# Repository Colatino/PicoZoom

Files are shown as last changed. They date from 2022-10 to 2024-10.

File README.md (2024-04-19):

# PicoZoom

A MIDI controller for Zoom pedals based on the Raspberry pi Pico.
 
This project is the microcontroler version of the [one](https://github.com/Colatino/ZeroPedal) I've built with a Raspberry Pi Zero

The purpose of this project is to build an auxiliary pedal controller to be used with Zoom multi-effects processors like the G1XFour (tested with this model) and be able to toggle individual effects on/off, add a tap-tempo functionality, among other possible features.

This project wouldn't be possible without [zoom-zt2](https://github.com/mungewell/zoom-zt2) and [ZoomPedalFun](https://github.com/shooking/ZoomPedalFun).

## HOW TO BUILD ONE

### CODE
You'll have to install the [Arduino IDE](https://www.arduino.cc/en/software) and add the [Arduino-pico core](https://github.com/earlephilhower/arduino-pico) to it, follow the [installation instructions](https://arduino-pico.readthedocs.io/en/latest/install.html) on the documentation. Tested with version 2.5, newer versions may not be compatible.

This project makes use of the following libraries:
- A custom version of [Adafruit_TinyUSB_Arduino](https://github.com/adafruit/Adafruit_TinyUSB_Arduino) based on [rppicomidi's fork](https://github.com/rppicomidi/tinyusb/tree/pio-midihost) of [tinyusb](https://github.com/hathach/tinyusb)
- [Adafruit_SSD1306](https://github.com/adafruit/Adafruit_SSD1306) and its dependencies
- [Arduino MIDI](https://github.com/FortySevenEffects/arduino_midi_library)

Copy the custom [Adafruit_TinyUSB_Arduino](https://github.com/Colatino/PicoZoom/tree/main/lib/Adafruit_TinyUSB_Library) library to you Arduino/libraries folder, be careful if you already have the original one installed as it will be overwritten.

Open the *.ino file and change whatever lines you need, you might want to change these lines to match your setup:
```cpp
#define NUM_PEDALS 5 // Number of switches and screens - for now each switch has to be linked to an oled screen
int switch_pins[] = { 5, 6, 7, 8, 9 }; // GPIO pins on the pico the switches are attached to 
FootSwitch footswitch[NUM_PEDALS];

int buses[] = { 7, 6, 5, 4, 3 }; // Buses on the TCA9548A the oled screens are attached to
Oled oleds[NUM_PEDALS];
```

For the G1XFour (possibly also the G1Four) no other line has to be changed.

On the IDE, go to Tools -> Board and select the Raspberry Pi Pico board (or other compatible) and select the appropriate comm Port. 

Then again Tools -> CPU Speed and set it to 120 MHz (this is crucial for the USB over PIO) and Tools -> USB Stack and set it to Adafruit TinyUSB.

Click upload and it will be compiled and sent to the board. 

If the IDE can't find the board, unplug it, hold the Bootsel button and plug it again. The PC will recognize it as a flash drive then on the IDE go to Sketch -> Export compiled binary and, after it is compiled, go to the sketch's folder and into the build folder look for the .UF2 file and drag and drop it on the Pico drive, all done.

### HARDWARE

To build it you'll need the following (G1XFour/G1Four):
- 1 x Raspberry Pi Pico (or a RP2040 based board)
- 5 x SSD1306 0.91" oled displays
- 1 x TC9548A
- 5 x SPST momentary footswitches
- 1 x female USB type A breakout board
- Some jumper wires
- Some box or case to contain everything - mine will be 3d printed and the files available on the case folder

Follow this wiring diagram (change GPIO if needed)
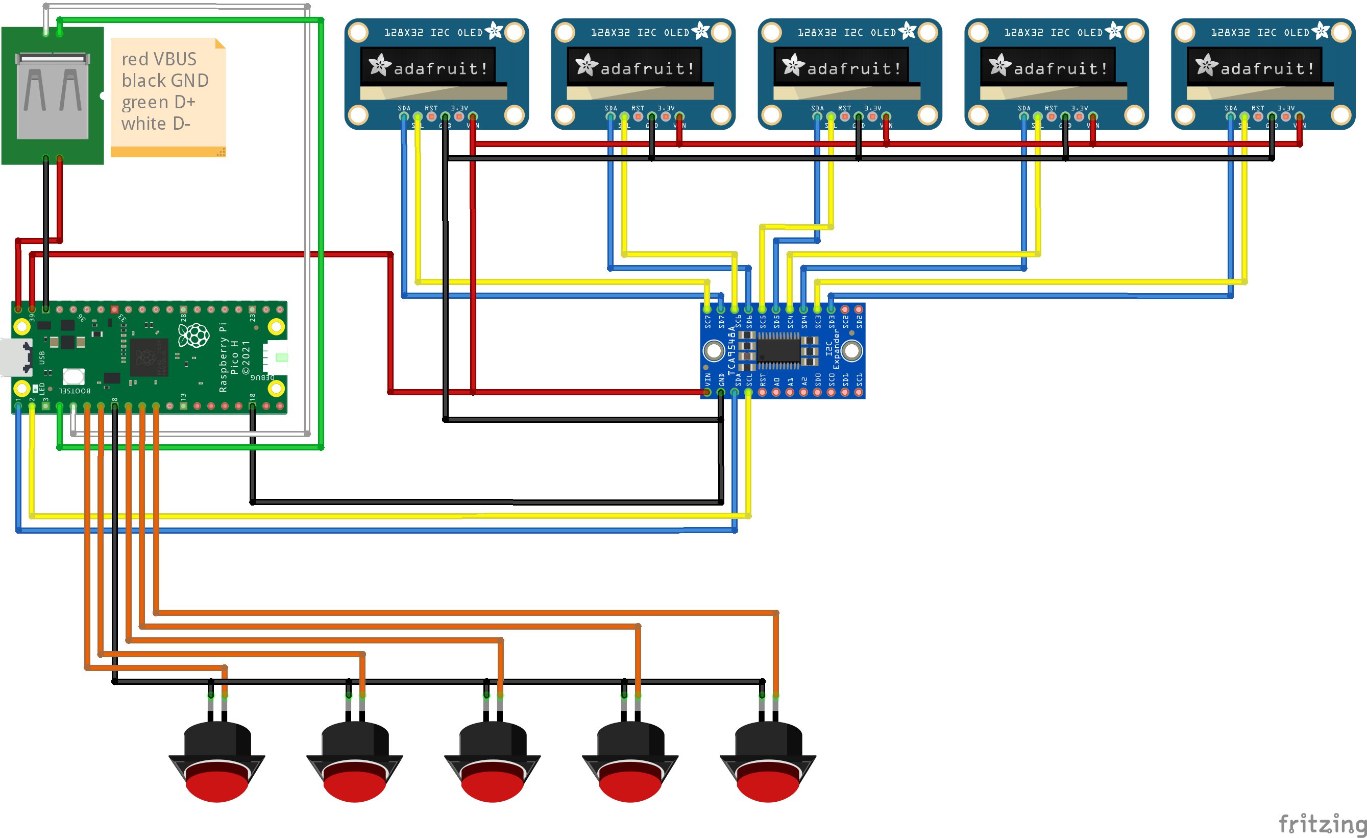
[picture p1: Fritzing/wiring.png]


I recommend not to use headers but instead solder the jumper wires to the TCA9548A as it may, sometimes, get loose.

After all the connections are made, I recommend that before you assembly the controller, test it with the Pedal as it will be harder to debug later.

If all goes well, just put everything inside the box ([stl/3mf files for 3d printing](https://github.com/Colatino/PicoZoom/tree/main/Case)) and you're done!

## How to use

Power the controller through the Pico's micro USB port (5V required, 1+ amps prefered) then connect it to the Pedal's own micro USB. The controller will provide power to the pedal and then it will read the pedal's data and show the current patch effects on the OLED screens. 

### Toggling effects

To toggle individual effects on/off just step on the corresponding switch, an active effect will have its name visible like -DELAY-, while an inactive one will have a strikethrough like ~~-DELAY-~~.

This is a video showing how it behaves when plugging and toggling effects:
Sample video (https://www.youtube.com/watch?v=8XPy8AvLA0o)

### Tap tempo/BPM

The tap tempo feature works when you have a delay effect on the current patch. 
To use it you'll have to hold its corresponding footswitch for at least 1 second, the OLED screen will then show the message *TAP TEMPO*, then you just have to press/tap the switch at the desire interval and the controller will show the current measured time between taps. When you're satisfied just stop tapping and wait for 3 seconds, the controller will send the measured interval to the pedal and will go back to the normal functions, showing the effect's name again. See the video bellow for a sample of how it works:

Tap tempo sample (https://youtu.be/NjomxG56lNE)

The global BPM feature works similarly but will ONLY be enabled when holding on any switch the DOES NOT correspond to a delay effect for 1 second. After activated a message *GLOBAL BPM* will show on the screen, then you just have to press/tap the switch at the desire interval and the controller will calculate the BPMs corresponding to that interval and show it on the screen. When you're satisfied just stop tapping and wait for 3 seconds, the controller will send the measured interval to the pedal and will go back to the normal functions, showing the effect's name again. See the video bellow for a sample of how it works:

Global tempo sample (https://youtu.be/VsWXhOvHJVc)

### ROADMAP
- [x] Ensure USB communications
- [x] Detect pedal plug/unplug
- [x] Handle MIDI packets
  - [x] Get pedal model/vid/pid
  - [x] Get current patch
    - [x] Get current patch effects state (on/off)
    - [x] Set current patch effect state (on/off)    
  - [x] Implement tap tempo
  - [x] Implement change global BPM
- [x] Handle footswitch press
- [x] Handle OLEDs
- [x] Create wiring diagram
- [x] Record and publish sample videos
- [x] Write a step-by-step guide
- [ ] Improve README
- [ ] Support other Zoom pedals by default?
- [ ] Add a battery?

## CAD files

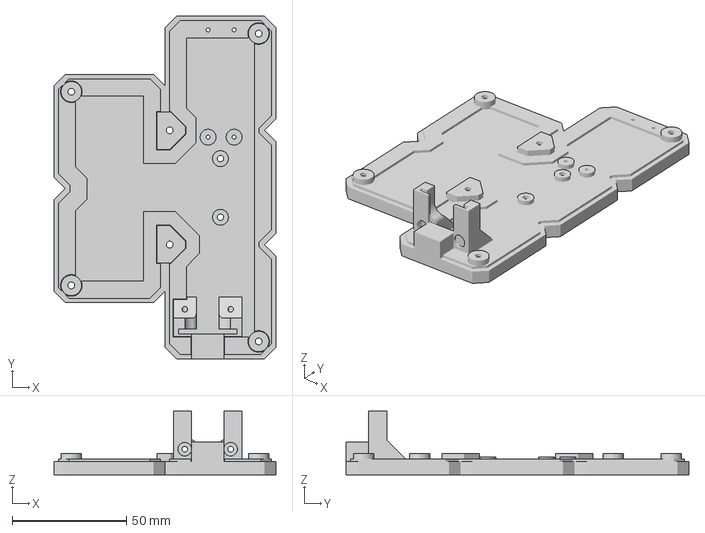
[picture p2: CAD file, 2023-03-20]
case/basev2.3mf
97.2 x 150.0 x 28.0 mm

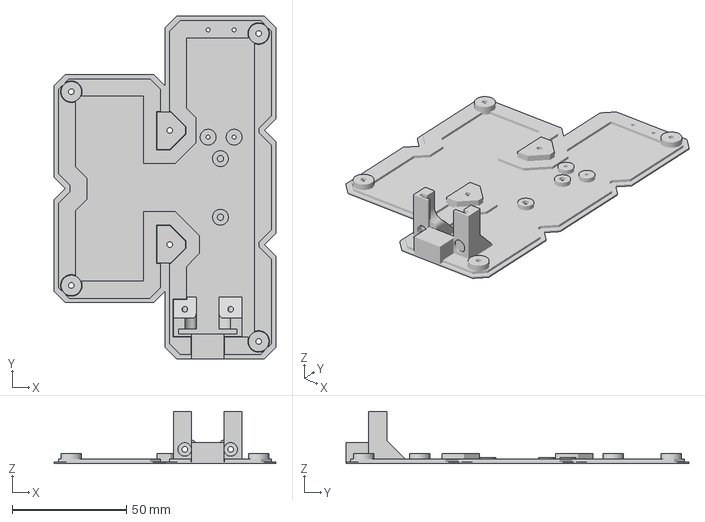
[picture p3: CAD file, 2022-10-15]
Case/base.3mf
97.2 x 150.0 x 23.0 mm

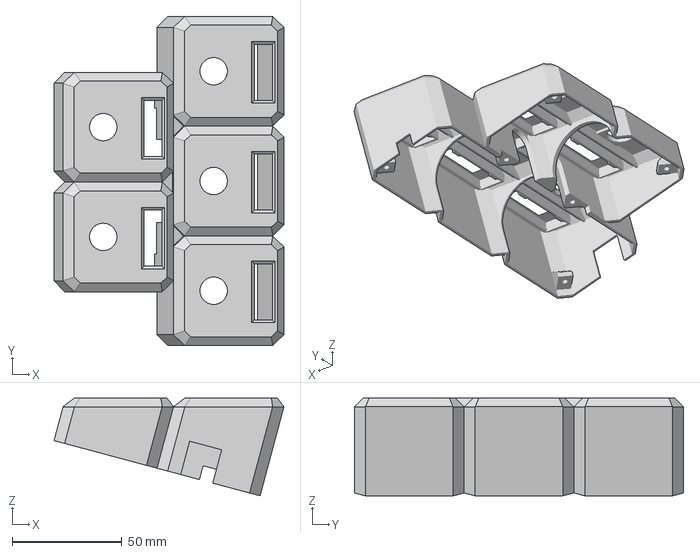
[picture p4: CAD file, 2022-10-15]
Case/top.3mf
104.8 x 150.0 x 44.5 mm

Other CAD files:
Case/base.stl
Case/top.stl
case/basev2.stl

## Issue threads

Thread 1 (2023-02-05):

Compile error on " function 'void poll_midi_host_rx()"

MarcosHAC, 2023-02-05:
Hi

this is a great project. It will help me play at church for sure. I got all the libraries and dependencies I found ([Adafruit_TinyUSB_Arduino](https://github.com/adafruit/Adafruit_TinyUSB_Arduino), [Pico-PIO-USB](https://github.com/sekigon-gonnoc/Pico-PIO-USB), [Adafruit_SSD1306](https://github.com/adafruit/Adafruit_SSD1306), [Adafruit-GFX-Library](https://github.com/adafruit/Adafruit-GFX-Library), [Adafruit_BusIO](https://github.com/adafruit/Adafruit_BusIO), [arduino_midi_library](https://github.com/FortySevenEffects/arduino_midi_library)). I also selected the board as instructed on Github (Pico). When I do a Verify on the code, I am getting the following error. It seems either a declare is nissing n the code, or I have a missing library. Please help to get this fixed. Thank you.

Arduino: 1.8.19 (Linux), Board: "Raspberry Pi Pico, 2MB (no FS), 120 MHz, Small (-Os) (standard), Disabled, Disabled, Disabled, Disabled, None, Adafruit TinyUSB, IPv4 Only, Default (UF2)"

../Documents/Pedal/beta/beta.ino: In function 'void poll_midi_host_rx()':
beta:771:10: error: 'tuh_midi_configured' was not declared in this scope; did you mean 'tuh_configure'?
  771 |     if (!tuh_midi_configured(midi_dev_addr)) {
      |          ^~~~~~~~~~~~~~~~~~~
      |          tuh_configure
beta:777:9: error: 'tuh_midih_get_num_rx_cables' was not declared in this scope
  777 |     if (tuh_midih_get_num_rx_cables(midi_dev_addr) < 1) {
      |         ^~~~~~~~~~~~~~~~~~~~~~~~~~~
beta:781:5: error: 'tuh_midi_read_poll' was not declared in this scope; did you mean 'tud_midi_read'?
  781 |     tuh_midi_read_poll(midi_dev_addr);
      |     ^~~~~~~~~~~~~~~~~~
      |     tud_midi_read
/home/marcos/Documents/Pedal/beta/beta.ino: In function 'void midi_host_task()':
beta:790:5: error: 'tuh_midi_stream_flush' was not declared in this scope; did you mean 'tud_midi_stream_write'?
  790 |     tuh_midi_stream_flush(midi_dev_addr);
      |     ^~~~~~~~~~~~~~~~~~~~~
      |     tud_midi_stream_write
/home/marcos/Documents/Pedal/beta/beta.ino: In function 'void send_sysex(uint8_t*, int)':
beta:878:5: error: 'tuh_midi_packet_write' was not declared in this scope; did you mean 'tud_midi_packet_write'?
  878 |     tuh_midi_packet_write(midi_dev_addr, packet);
      |     ^~~~~~~~~~~~~~~~~~~~~
      |     tud_midi_packet_write
/home/marcos/Documents/Pedal/beta/beta.ino: In function 'void tuh_midi_rx_cb(uint8_t, uint32_t)':
beta:930:11: error: 'tuh_midi_packet_read' was not declared in this scope; did you mean 'tud_midi_packet_read'?
  930 |       if (tuh_midi_packet_read(dev_addr, packet)) {
      |           ^~~~~~~~~~~~~~~~~~~~
      |           tud_midi_packet_read

'tuh_midi_configured' was not declared in this scope; did you mean 'tuh_configure'?

Colatino, 2023-02-05:
Hey Marcos, I will gladly help you!

It seems that you're not using my modified Adafruit_tinyusb library. Later today I'll have a look at it and try to come with a solution.

MarcosHAC, 2023-02-05:
Obrigado pela dica!!

I replaced the github tinyusb library with the one you provided and code is now compiling!!! Thank you!!!!

Colatino, 2023-02-05:
> Obrigado pela dica!!
>
> I replaced the github tinyusb library with the one you provided and code is now compiling!!! Thank you!!!!

Glad I could be of help.

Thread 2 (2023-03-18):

Ajuda com codigo

Bassgomes, 2023-03-18:
Olá André, estou com dificuldades de fazer o codigo funcionar

Bassgomes, 2023-03-18:
Primeiro erro foi de pio_usb.h, então procurei na biblioteca do arduino e encontrei uma e instalei, até que corrigiu esse erro.. agora apareceu outro...

C:\Users\bassg\Desktop\PicoZoom-main\src\beta\beta.ino: In function 'void poll_midi_host_rx()':
C:\Users\bassg\Desktop\PicoZoom-main\src\beta\beta.ino:771:10: error: 'tuh_midi_configured' was not declared in this scope; did you mean 'tuh_configure'?
  771 |     if (!tuh_midi_configured(midi_dev_addr)) {
      |          ^~~~~~~~~~~~~~~~~~~
      |          tuh_configure
C:\Users\bassg\Desktop\PicoZoom-main\src\beta\beta.ino:777:9: error: 'tuh_midih_get_num_rx_cables' was not declared in this scope
  777 |     if (tuh_midih_get_num_rx_cables(midi_dev_addr) < 1) {
      |         ^~~~~~~~~~~~~~~~~~~~~~~~~~~
C:\Users\bassg\Desktop\PicoZoom-main\src\beta\beta.ino:781:5: error: 'tuh_midi_read_poll' was not declared in this scope; did you mean 'tud_midi_read'?
  781 |     tuh_midi_read_poll(midi_dev_addr);
      |     ^~~~~~~~~~~~~~~~~~
      |     tud_midi_read
C:\Users\bassg\Desktop\PicoZoom-main\src\beta\beta.ino: In function 'void midi_host_task()':
C:\Users\bassg\Desktop\PicoZoom-main\src\beta\beta.ino:790:5: error: 'tuh_midi_stream_flush' was not declared in this scope; did you mean 'tud_midi_stream_write'?
  790 |     tuh_midi_stream_flush(midi_dev_addr);
      |     ^~~~~~~~~~~~~~~~~~~~~
      |     tud_midi_stream_write
C:\Users\bassg\Desktop\PicoZoom-main\src\beta\beta.ino: In function 'void send_sysex(uint8_t*, int)':
C:\Users\bassg\Desktop\PicoZoom-main\src\beta\beta.ino:878:5: error: 'tuh_midi_packet_write' was not declared in this scope; did you mean 'tud_midi_packet_write'?
  878 |     tuh_midi_packet_write(midi_dev_addr, packet);
      |     ^~~~~~~~~~~~~~~~~~~~~
      |     tud_midi_packet_write
C:\Users\bassg\Desktop\PicoZoom-main\src\beta\beta.ino: In function 'void tuh_midi_rx_cb(uint8_t, uint32_t)':
C:\Users\bassg\Desktop\PicoZoom-main\src\beta\beta.ino:930:11: error: 'tuh_midi_packet_read' was not declared in this scope; did you mean 'tud_midi_packet_read'?
  930 |       if (tuh_midi_packet_read(dev_addr, packet)) {
      |           ^~~~~~~~~~~~~~~~~~~~
      |           tud_midi_packet_read
Multiple libraries were found for "Adafruit_TinyUSB.h"
  Used: C:\Users\bassg\AppData\Local\Arduino15\packages\rp2040\hardware\rp2040\3.1.0\libraries\Adafruit_TinyUSB_Arduino
  Not used: C:\Users\bassg\AppData\Local\Arduino15\libraries\Adafruit_TinyUSB_Library
exit status 1

Compilation error: 'tuh_midi_configured' was not declared in this scope; did you mean 'tuh_configure'?

Bassgomes, 2023-03-18:
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

Colatino, 2023-03-18:
Aparentemente você está tendo o mesmo problema que a issue #1. Suspeito que você não está usando a biblioteca Adafruit_TinyUSB customizada.

A biblioteca está na pasta "lib" dentro do projeto. Copie a pasta inteira e cole na pasta "libraries" do Arduino e veja se resolve o problema da compilação.

Colatino, 2025-10-07:
Você está usando a release 5.0 do ArduinoPico, tente desinstalar e reinstalar a versão 2.5 (ou fazer o downgrade para a versão 2.5), que foi a que eu usei quando estava desenvolvendo o projeto. Creio que no  próprio Ardiono IDE você consegue fazer através do Boards Manager (apontei isso no #9 )

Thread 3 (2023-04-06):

Memory -> Stomp -> Edit sysex

tdroxler, 2023-04-06:
Hi,

I'm starting to play with my G1X four (I'm better at coding that playing guitar, so I need an excuse not to practice my scales :stuck_out_tongue_closed_eyes: )

You did an amazing job here.

Do you know by any chance the `sysex` code to switch between the `Memory -> Stomp -> Edit` modes?

Thx a lot,

Cheers

Colatino, 2023-04-14:
There isn't a documented sysex to cycle through screens... I've discussed this matter with the guys that cracked the communications protocol and they also didn't find one.

You could change the board by soldering a momentary pushbutton to the terminals of the one that does the cycling.. but no coding there...

tdroxler, 2023-04-14:
Thx for your answer.

I take the opportunity for another question then. From what I found playing with wireshark and on some other resources on internet, there are some sysex to change to specific patches, but do we have a way to select any of the patches, the same way you nicely toggle the effect here?
https://github.com/Colatino/PicoZoom/blob/45fa947c4a9f63ee26ab7b70de7b5f0f8d13f39b/src/beta/beta.ino#L409-L410

tdroxler, 2023-04-14:
actually from [this video](https://www.youtube.com/watch?v=jKNqQNcffFs) I could easily find them all

```sh
#/bin/sh
for bank in {0..4}
do
  for patch in {0..9}
  do
    echo "f0b00000b0200${bank}c000f7f0cc0${patch}f7"
  done
done
```

Thx again for your amazing work, this helped me a lot to understand this all midi/sysex world.

Closed 2023-04-14.

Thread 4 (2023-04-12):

Compilation fatal error: pico/stdio.h: No such file or directory

ojungleboy, 2023-04-12:
Hi, I am pretty sure this is a newbie/environment related problem as this is my first time using Pico and Raspberry. I have several projects in ESP32.

The following error is happening when  compiling the code:

In file included from e:\Users\Jungle Boy\Documents\Arduino\libraries\Pico_PIO_USB\src\pio_usb.c:17:0:
C:\Users\Jungle Boy\AppData\Local\Arduino15\packages\arduino\hardware\mbed_rp2040\4.0.2\cores\arduino/mbed/targets/TARGET_RASPBERRYPI/TARGET_RP2040/pico-sdk/common/pico_stdlib/include/pico/stdlib.h:11:10: fatal error: pico/stdio.h: No such file or directory
 #include "pico/stdio.h"

 I already tried to reinstal SDK but no luck. Anyone can please give me some light??

Thanks

Colatino, 2023-04-14:
Are you using [this one](https://github.com/earlephilhower/arduino-pico)?

This project doesn't use the official Arduino installation (the mbed one)

Installin through the Arduino IDE you'll have to choose this one
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

ojungleboy, 2023-04-14:
Thanks for your answer. I tried both one and it does a similar problem on the stdio and stdlib libraries

ojungleboy, 2023-04-14:
I tried several board and this was the last one I choose. But it keep the same error on both boards as I mentioned

ojungleboy, 2023-04-14:
I reinstalled the environment and it seems that the error regarding the Adafruit Tiny USBLibrary. It looks that the custom library is conflicting with the RP2040 one.

Any idea how to solve it? Thanks!

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

ojungleboy, 2023-04-14:
A wise man told me to use the search and I realized that I had the same isse as issue #1

Now it is compiling and thank you once again!

Closed 2023-04-14.

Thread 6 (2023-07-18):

pico_usb.h is mising ?

pandeagus, 2023-07-18:
hello colatino how i fix pico_usb.h is no such file and directory..

and can i make this midi pedal without lcd.. what code i must modify?
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
 modify

Colatino, 2023-07-18:
Hey there!

Try installing this library https://reference.arduino.cc/reference/en/libraries/pico-pio-usb/

kaioffabio, 2024-03-21:
Hello Colatino!
Firstly congratulations on the project!

I was having the same problems above, but now I'm having new problems, if possible I would like your help with the error below:

I have already installed all the libraries mentioned in the forum

C:\Users\Administrador\OneDrive\Guita\TAP_TEMPO_G1Four\programa_ide\beta\beta\beta.ino: In function 'void poll_midi_host_rx()':
C:\Users\Administrador\OneDrive\Guita\TAP_TEMPO_G1Four\programa_ide\beta\beta\beta.ino:771:10: error: 'tuh_midi_configured' was not declared in this scope; did you mean 'tuh_configure'?
  771 |     if (!tuh_midi_configured(midi_dev_addr)) {
      |          ^~~~~~~~~~~~~~~~~~~
      |          tuh_configure
C:\Users\Administrador\OneDrive\Guita\TAP_TEMPO_G1Four\programa_ide\beta\beta\beta.ino:777:9: error: 'tuh_midih_get_num_rx_cables' was not declared in this scope
  777 |     if (tuh_midih_get_num_rx_cables(midi_dev_addr) < 1) {
      |         ^~~~~~~~~~~~~~~~~~~~~~~~~~~
C:\Users\Administrador\OneDrive\Guita\TAP_TEMPO_G1Four\programa_ide\beta\beta\beta.ino:781:5: error: 'tuh_midi_read_poll' was not declared in this scope; did you mean 'tud_midi_read'?
  781 |     tuh_midi_read_poll(midi_dev_addr);
      |     ^~~~~~~~~~~~~~~~~~
      |     tud_midi_read
C:\Users\Administrador\OneDrive\Guita\TAP_TEMPO_G1Four\programa_ide\beta\beta\beta.ino: In function 'void midi_host_task()':
C:\Users\Administrador\OneDrive\Guita\TAP_TEMPO_G1Four\programa_ide\beta\beta\beta.ino:790:5: error: 'tuh_midi_stream_flush' was not declared in this scope; did you mean 'tud_midi_stream_write'?
  790 |     tuh_midi_stream_flush(midi_dev_addr);
      |     ^~~~~~~~~~~~~~~~~~~~~
      |     tud_midi_stream_write
C:\Users\Administrador\OneDrive\Guita\TAP_TEMPO_G1Four\programa_ide\beta\beta\beta.ino: In function 'void send_sysex(uint8_t*, int)':
C:\Users\Administrador\OneDrive\Guita\TAP_TEMPO_G1Four\programa_ide\beta\beta\beta.ino:878:5: error: 'tuh_midi_packet_write' was not declared in this scope; did you mean 'tud_midi_packet_write'?
  878 |     tuh_midi_packet_write(midi_dev_addr, packet);
      |     ^~~~~~~~~~~~~~~~~~~~~
      |     tud_midi_packet_write
C:\Users\Administrador\OneDrive\Guita\TAP_TEMPO_G1Four\programa_ide\beta\beta\beta.ino: In function 'void tuh_midi_rx_cb(uint8_t, uint32_t)':
C:\Users\Administrador\OneDrive\Guita\TAP_TEMPO_G1Four\programa_ide\beta\beta\beta.ino:930:11: error: 'tuh_midi_packet_read' was not declared in this scope; did you mean 'tud_midi_packet_read'?
  930 |       if (tuh_midi_packet_read(dev_addr, packet)) {
      |           ^~~~~~~~~~~~~~~~~~~~
      |           tud_midi_packet_read
Multiple libraries were found for "Adafruit_TinyUSB.h"
  Used: C:\Users\Administrador\OneDrive\Documentos\Arduino\libraries\Adafruit_TinyUSB_Library
  Not used: C:\Users\Administrador\AppData\Local\Arduino15\packages\rp2040\hardware\rp2040\3.7.2\libraries\Adafruit_TinyUSB_Arduino
exit status 1

Compilation error: 'tuh_midi_configured' was not declared in this scope; did you mean 'tuh_configure'?

Colatino, 2024-03-21:
Hey @kaioffabio !

It seems that you're having the same problem as #1 , you didn't install my custom Adafruit_tinyusb library as per the instructions on the project page:

"Copy the custom [Adafruit_TinyUSB_Arduino](https://github.com/Colatino/PicoZoom/tree/main/lib/Adafruit_TinyUSB_Library) library to you Arduino/libraries folder, be careful if you already have the original one installed as it will be overwritten."

Can you try that and see if it works?

kaioffabio, 2024-03-21:
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

Friend, I already copied and pasted it into the Arduino folder.
Can you check if I glued it to the right dough, please?

kaioffabio, 2024-03-22:
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

I reinstalled the modified library, now this error appears

Colatino, 2024-03-22:
I can't reproduce the error on my machine but maybe you have newer libraries than I do, as this project.

One thing you could do to try and clarify the issue is enabling "Verbose" during compile:
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

There is a solution but only feasible if you're using the same exact hardware as I am (G1XFour, Original RPi Pico, multiplexers, oleds), following the wiring diagram and using also the same pins. The solution is downloading the already compiled _.uf2_ file to upload to you pico, it is available on the [releases](https://github.com/Colatino/PicoZoom/releases) page.

If you want to try it, just press _bootsel_ button while plugging in the USB cable, the pico should be seen as a flash drive, now you just need to drag the _.uf2_ file into it. If everything goes well the pico will reset and start with the new firmware.

kaioffabio, 2024-03-23:
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

Friend, can you help me remotely?
If it doesn't bother you, of course...
My Whatsapp
31994930228

kaioffabio, 2024-03-26:
Good morning my friend!

My doubts are about this direct loading of the already compiled program that you mentioned.
I bought the same hardware that you mention in the video, I believe this method will be ideal.
When I drag the program into the controller it would be as if it restarted, but I have no answer as to whether everything went well.
I have some questions about the connections, my display doesn't light up the screen, do I need to use an external source?

GhermanX, 2024-10-08:
Boa noite @kaioffabio, você conseguiu resolver o ultimo problema que citou ai?

Colatino, 2024-10-08:
> Good morning my friend!
>
> My doubts are about this direct loading of the already compiled program that you mentioned. I bought the same hardware that you mention in the video, I believe this method will be ideal. When I drag the program into the controller it would be as if it restarted, but I have no answer as to whether everything went well. I have some questions about the connections, my display doesn't light up the screen, do I need to use an external source?

The only feedback you get is when the Oled screens light up and show white a line.

The usb cable would be enough to make it show these white lines on the oleds but you should supply power by the other usb connection that is described on the diagram.

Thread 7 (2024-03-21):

Erro ao salvar o código no raspberry

eubin999, 2024-03-21:
Chefe, está dando o seguinte erro ao fazer o upload do código, consegue me ajudar

D:\PicoZoom-main\PicoZoom-main\src\beta\footswitch.cpp: In member function 'foot_switch_state_t FootSwitch::task()':
D:\PicoZoom-main\PicoZoom-main\src\beta\footswitch.cpp:47:33: warning: comparison of integer expressions of different signedness: 'long unsigned int' and 'int' [-Wsign-compare]
   47 |       if (_trigger_time - _time >= _debounce_time) {
      |           ~~~~~~~~~~~~~~~~~~~~~~^~~~~~~~~~~~~~~~~
D:\PicoZoom-main\PicoZoom-main\src\beta\footswitch.cpp:61:28: warning: comparison of integer expressions of different signedness: 'long unsigned int' and 'int' [-Wsign-compare]
   61 |       if (millis() - _time > _debounce_time) {
      |           ~~~~~~~~~~~~~~~~~^~~~~~~~~~~~~~~~
D:\PicoZoom-main\PicoZoom-main\src\beta\footswitch.cpp:74:17: warning: comparison of integer expressions of different signedness: 'long unsigned int' and 'int' [-Wsign-compare]
   74 |       if (tempo >= _debounce_time) {
      |           ~~~~~~^~~~~~~~~~~~~~~~~
D:\Hebert\PicoZoom-main\PicoZoom-main\src\beta\footswitch.cpp:94:17: warning: comparison of integer expressions of different signedness: 'long unsigned int' and 'int' [-Wsign-compare]
   94 |       if (tempo >= _debounce_time) {
      |           ~~~~~~^~~~~~~~~~~~~~~~~
In file included from D:\Hebert\PicoZoom-main\PicoZoom-main\src\beta\oled.cpp:27:
D:\PicoZoom-main\PicoZoom-main\src\beta\oled.h:1:10: error: expected constructor, destructor, or type conversion before '(' token
    1 |  License (MIT)
      |          ^
D:\PicoZoom-main\PicoZoom-main\src\beta\oled.cpp: In member function 'void Oled::draw_tempo(int, const char*)':
D:\PicoZoom-main\PicoZoom-main\src\beta\oled.cpp:115:12: warning: unused variable 'w' [-Wunused-variable]
  115 |   uint16_t w, h;
      |            ^
D:\Hebert\PicoZoom-main\PicoZoom-main\src\beta\oled.cpp:115:15: warning: unused variable 'h' [-Wunused-variable]
  115 |   uint16_t w, h;
      |               ^
D:\Hebert\PicoZoom-main\PicoZoom-main\src\beta\oled.cpp:116:11: warning: unused variable 'x1' [-Wunused-variable]
  116 |   int16_t x1, y1;
      |           ^~
D:\Hebert\PicoZoom-main\PicoZoom-main\src\beta\oled.cpp:116:15: warning: unused variable 'y1' [-Wunused-variable]
  116 |   int16_t x1, y1;
      |               ^~
In file included from D:\Hebert\PicoZoom-main\PicoZoom-main\src\beta\beta.ino:49:
D:\Hebert\PicoZoom-main\PicoZoom-main\src\beta\oled.h:1:10: error: expected constructor, destructor, or type conversion before '(' token
    1 |  License (MIT)
      |          ^
In file included from c:\Users\heber\OneDrive\Documentos\Arduino\libraries\Adafruit_GFX_Library/Adafruit_GFX.h:10,
                 from D:\Hebert\PicoZoom-main\PicoZoom-main\src\beta\oled.h:30:
c:\Users\heber\OneDrive\Documentos\Arduino\libraries\Adafruit_GFX_Library/gfxfont.h:18:3: error: 'GFXglyph' does not name a type
   18 | } GFXglyph;
      |   ^~~~~~~~
c:\Users\heber\OneDrive\Documentos\Arduino\libraries\Adafruit_GFX_Library/gfxfont.h:23:3: error: 'GFXglyph' does not name a type
   23 |   GFXglyph *glyph;  ///< Glyph array
      |   ^~~~~~~~
D:\Hebert\PicoZoom-main\PicoZoom-main\src\beta\beta.ino: In function 'void parse_patch()':
D:\Hebert\PicoZoom-main\PicoZoom-main\src\beta\beta.ino:248:9: warning: unused variable 'edtb_end' [-Wunused-variable]
  248 |     int edtb_end = find_section_index("PPRM");
      |         ^~~~~~~~
D:\PicoZoom-main\PicoZoom-main\src\beta\beta.ino: In function 'void parse_sysex()':
D:\PicoZoom-main\PicoZoom-main\src\beta\beta.ino:343:15: warning: unused variable 'tempo' [-Wunused-variable]
  343 |           int tempo = high ? 128 + low : low;
      |               ^~~~~
D:\PicoZoom-main\PicoZoom-main\src\beta\beta.ino: In function 'void isr()':
D:\PicoZoom-main\PicoZoom-main\src\beta\beta.ino:365:17: warning: unused variable 'aux_time' [-Wunused-variable]
  365 |   unsigned long aux_time = millis();
      |                 ^~~~~~~~
D:\Hebert\PicoZoom-main\PicoZoom-main\src\beta\beta.ino: In function 'void handle_footswitch_states_and_tasks()':
D:\Hebert\PicoZoom-main\PicoZoom-main\src\beta\beta.ino:432:37: warning: suggest parentheses around '&&' within '||' [-Wparentheses]
  432 |             if (temp_state == TEMPO && strcmp(pname, "Time") == 0 || strcmp(pname, "TimeA") == 0) {
      |                 ~~~~~~~~~~~~~~~~~~~~^~~~~~~~~~~~~~~~~~~~~~~~~~~~~
D:\PicoZoom-main\PicoZoom-main\src\beta\beta.ino:478:21: warning: unused variable 'tempo' [-Wunused-variable]
  478 |       unsigned long tempo = footswitch[i].get_tempo();
      |                     ^~~~~
D:\PicoZoom-main\PicoZoom-main\src\beta\beta.ino: In function 'void tuh_midi_mount_cb(uint8_t, uint8_t, uint8_t, uint8_t, uint16_t)':
D:\PicoZoom-main\PicoZoom-main\src\beta\beta.ino:803:47: warning: unused parameter 'in_ep' [-Wunused-parameter]
  803 | void tuh_midi_mount_cb(uint8_t daddr, uint8_t in_ep, uint8_t out_ep, uint8_t num_cables_rx, uint16_t num_cables_tx) {
      |                                       ~~~~~~~~^~~~~
D:\PicoZoom-main\PicoZoom-main\src\beta\beta.ino:803:62: warning: unused parameter 'out_ep' [-Wunused-parameter]
  803 | void tuh_midi_mount_cb(uint8_t daddr, uint8_t in_ep, uint8_t out_ep, uint8_t num_cables_rx, uint16_t num_cables_tx) {
      |                                                      ~~~~~~~~^~~~~~
D:\Hebert\PicoZoom-main\PicoZoom-main\src\beta\beta.ino:803:78: warning: unused parameter 'num_cables_rx' [-Wunused-parameter]
  803 | void tuh_midi_mount_cb(uint8_t daddr, uint8_t in_ep, uint8_t out_ep, uint8_t num_cables_rx, uint16_t num_cables_tx) {
      |                                                                      ~~~~~~~~^~~~~~~~~~~~~
D:\PicoZoom-main\PicoZoom-main\src\beta\beta.ino:803:102: warning: unused parameter 'num_cables_tx' [-Wunused-parameter]
  803 | void tuh_midi_mount_cb(uint8_t daddr, uint8_t in_ep, uint8_t out_ep, uint8_t num_cables_rx, uint16_t num_cables_tx) {
      |                                                                                             ~~~~~~~~~^~~~~~~~~~~~~
D:\Hebert\PicoZoom-main\PicoZoom-main\src\beta\beta.ino: In function 'void tuh_umount_cb(uint8_t)':
D:\Hebert\PicoZoom-main\PicoZoom-main\src\beta\beta.ino:809:28: warning: unused parameter 'daddr' [-Wunused-parameter]
  809 | void tuh_umount_cb(uint8_t daddr) {
      |                    ~~~~~~~~^~~~~
D:\PicoZoom-main\PicoZoom-main\src\beta\beta.ino: In function 'void send_sysex(uint8_t*, int)':
D:\PicoZoom-main\PicoZoom-main\src\beta\beta.ino:856:23: warning: statement has no effect [-Wunused-value]
  856 |             packet[0] == 0x05;
      |             ~~~~~~~~~~^~~~~~~
D:\PicoZoom-main\PicoZoom-main\src\beta\beta.ino:859:23: warning: statement has no effect [-Wunused-value]
  859 |             packet[0] == 0x06;
      |             ~~~~~~~~~~^~~~~~~
D:\PicoZoom-main\PicoZoom-main\src\beta\beta.ino: In function 'void tuh_midi_rx_cb(uint8_t, uint32_t)':
D:\PicoZoom-main\PicoZoom-main\src\beta\beta.ino:927:9: warning: unused variable 'i' [-Wunused-variable]
  927 |     int i = 1;
      |         ^
D:\PicoZoom-main\PicoZoom-main\src\beta\beta.ino: In function 'void clone_descriptors(tuh_xfer_t*)':
D:\PicoZoom-main\PicoZoom-main\src\beta\beta.ino:957:17: warning: unused variable 'daddr' [-Wunused-variable]
  957 |   uint8_t const daddr = xfer->daddr;
      |                 ^~~~~
Multiple libraries were found for "Adafruit_TinyUSB.h"
  Used: C:\Users\OneDrive\Documentos\Arduino\libraries\Adafruit_TinyUSB_Library
  Not used: C:\Users\AppData\Local\Arduino15\packages\rp2040\hardware\rp2040\3.7.2\libraries\Adafruit_TinyUSB_Arduino
Using library MIDI Library at version 5.0.2 in folder: C:\Users\OneDrive\Documentos\Arduino\libraries\MIDI_Library
Using library Pico PIO USB at version 0.5.3 in folder: C:\Users\OneDrive\Documentos\Arduino\libraries\Pico_PIO_USB
Using library Adafruit TinyUSB Library at version 1.14.3 in folder: C:\Users\heber\OneDrive\Documentos\Arduino\libraries\Adafruit_TinyUSB_Library
Using library Adafruit GFX Library at version 1.11.9 in folder: C:\Users\heber\OneDrive\Documentos\Arduino\libraries\Adafruit_GFX_Library
Using library Adafruit BusIO at version 1.15.0 in folder: C:\Users\heber\OneDrive\Documentos\Arduino\libraries\Adafruit_BusIO
Using library Wire at version 1.0 in folder: C:\Users\heber\AppData\Local\Arduino15\packages\rp2040\hardware\rp2040\3.7.2\libraries\Wire
Using library SPI at version 1.0 in folder: C:\Users\heber\AppData\Local\Arduino15\packages\rp2040\hardware\rp2040\3.7.2\libraries\SPI
Using library Adafruit SSD1306 at version 2.5.9 in folder: C:\Users\OneDrive\Documentos\Arduino\libraries\Adafruit_SSD1306
exit status 1

Compilation error: expected constructor, destructor, or type conversion before '(' token

Colatino, 2024-03-21:
Tem uns erros estranhos aí:

Esse aqui, por exemplo:
`In file included from D:\Hebert\PicoZoom-main\PicoZoom-main\src\beta\oled.cpp:27:
D:\PicoZoom-main\PicoZoom-main\src\beta\oled.h:1:10: error: expected constructor, destructor, or type conversion before '(' token
1 | License (MIT)`

Ele está identificando o comentário (linha iniciada com /*) como se fosse parte do código. Esse erro eu não consigo reproduzir aqui para tentar te ajudar.

Você seguiu os passos de instalação que eu citei na página inicial do projeto?
Fez alguma alteração no código? Talvez você tenha excluído algum a coisa.

eubin999, 2024-03-22:
Refiz novamente o procedimento, porém aparece o mesmo erro, segui passo a passo, mas sou leigo em programação.
Comprei o PICO, mas outro modelo, esse aqui, ele tem 16mb, quando encaixo no PC diz que tem 127mb

https://pt.aliexpress.com/item/1005006055009344.html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

Mas acho que não tem influência isso. Não sei se é falha em alguma biblioteca. Não alterei nenhuma linha, abri diretamente o arquivo beta.ino

FQBN: rp2040:rp2040:rpipico:freq=120,dbglvl=Core,usbstack=tinyusb
Using board 'rpipico' from platform in folder: C:\Users\heber\AppData\Local\Arduino15\packages\rp2040\hardware\rp2040\3.7.2
Using core 'rp2040' from platform in folder: C:\Users\heber\AppData\Local\Arduino15\packages\rp2040\hardware\rp2040\3.7.2
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

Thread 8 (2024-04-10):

error: redefinition of 'static uint8_t Adafruit_USBD_CDC::getInstanceCount()'

ThiagoMux, 2024-04-10:
@Colatino,

Em primeiro lugar obrigado por compartilhar o trabalho!!

Te escrevo pois ao tentar verificar/compilar o código estou recebendo um erro de múltiplas definições de um parâmetro. Como não conheço nada de programação e é minha primeira experiência com Arduíno imagino que possa ser algo mais simples do que parece.

c:\Users\Desktop\Documents\Arduino\libraries\Adafruit_TinyUSB_Library\src\arduino\Adafruit_USBD_CDC.cpp:50:9: error: redefinition of 'static uint8_t Adafruit_USBD_CDC::getInstanceCount()'
   50 | uint8_t Adafruit_USBD_CDC::getInstanceCount(void) { return _instance_count; }
      |         ^~~~~~~~~~~~~~~~~
In file included from C:\Users\Desktop\AppData\Local\Arduino15\packages\rp2040\hardware\rp2040\3.7.2\cores\rp2040/Arduino.h:115,
                 from c:\Users\Desktop\Documents\Arduino\libraries\Adafruit_TinyUSB_Library\src\arduino\Adafruit_USBD_CDC.cpp:29:
C:\Users\Desktop\AppData\Local\Arduino15\packages\rp2040\hardware\rp2040\3.7.2/libraries/Adafruit_TinyUSB_Arduino/src/arduino/Adafruit_USBD_CDC.h:46:18: note: 'static uint8_t Adafruit_USBD_CDC::getInstanceCount()' previously defined here
   46 |   static uint8_t getInstanceCount(void) { return _instance_count; }
      |                  ^~~~~~~~~~~~~~~~
Multiple libraries were found for "Adafruit_TinyUSB.h"
  Used: C:\Users\Desktop\Documents\Arduino\libraries\Adafruit_TinyUSB_Library
  Not used: C:\Users\Desktop\AppData\Local\Arduino15\packages\rp2040\hardware\rp2040\3.7.2\libraries\Adafruit_TinyUSB_Arduino
exit status 1

Compilation error: exit status 1

Passos realizados
- instalação do Arduino IDE
- ativação da placa PI PICO (VCC-GND YD RP2040) e seleção da frequência para 120 MHz e USB
- Instalação da bibliotecas
- substituição da biblioteca TinyUSB pela do arquivo (desinstalação da mais atual e inclusão via arquivo zip no Arduino IDE)
- abri o arquivo "Beta.ino" no Arduíno IDE e pedi para compilar

Em tempo, eu consigo conectar o PI PICO via USB e fazer os exemplos de piscar o LED

Consegue me dar uma orientação?

Obrigado,

Thiago

Colatino, 2024-04-10:
@ThiagoMux

Esse problema também foi relatado na #6 . Quando eu adaptei a biblioteca Adafruit TinyUSB, a original (que está incluída no core Arduino-Pico) ainda não tinha algumas das funções que precisei criar. Essa ```getInstanceCount``` é uma delas. Um outro ponto é a versão do core Arduino-Pico, que quando criei estava em algo como 2.4 e agora já passa da 3.7.

Talvez seja necessário readaptar as bibliotecas novamente e não estou tendo tempo livre o suficiente para isso no momento.

Minha sugestão seria fazer um downgrade da Arduino-Pico para uma versão próxima da 2.5 ou 2.7 e testar compilar novamente, pode ser que funcione.

ThiagoMux, 2024-04-10:
@Colatino ,

Obrigado pela resposta....fir o downgrade pra versão 2.50 e agora compilou sem erros.

Valeu e grande abraço!

Closed 2024-04-10.

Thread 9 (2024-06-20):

Adafruit_USBD_CDC.h error

cjnsario, 2024-06-20:
In file included from C:\Users\CJNS\AppData\Local\Temp\arduino\sketches\23D4F6FED3E93305B261E872E3B7ED67\sketch\beta.ino.cpp:1:
C:\Users\CJNS\AppData\Local\Arduino15\packages\rp2040\hardware\rp2040\3.9.3\cores\rp2040/Arduino.h:115:10: fatal error: Adafruit_USBD_CDC.h: No such file or directory
  115 | #include "Adafruit_USBD_CDC.h"
      |          ^~~~~~~~~~~~~~~~~~~~~
compilation terminated.
exit status 1

Compilation error: exit status 1

Please help. I'm getting this error even though I used the custom Adafruit_TinyUSB_Library

cjnsario, 2024-06-20:
Do you need to connect the electronic components first before uploading the code to the pico?

Colatino, 2024-06-20:
You don't have to connect the components to compile or upload the code.

You may try downgrading your Arduino-pico core to version 2.5 and try again.

cjnsario, 2024-06-20:
Tried installing 2.5, but no luck my friend. Still gives the same error:

In file included from C:\Users\CJNS\AppData\Local\Temp\arduino\sketches\4C227CEA44EA234455A3C8DA0790A71E\sketch\beta.ino.cpp:1:
C:\Users\CJNS\AppData\Local\Arduino15\packages\rp2040\hardware\rp2040\2.5.0\cores\rp2040/Arduino.h:106:10: fatal error: Adafruit_USBD_CDC.h: No such file or directory
  106 | #include "Adafruit_USBD_CDC.h"
      |          ^~~~~~~~~~~~~~~~~~~~~
compilation terminated.
exit status 1

Compilation error: exit status 1

Colatino, 2024-06-20:
For some reason the IDE is not finding the Adafruit_USBD_CDC.h file but the Arduino-Pico core comes with the standard one already preinstalled, this error should not appear even if you didn't copy the custom library to the Arduino/libraries folder.

Are you certain that you copied the library to the correct folder? It is usually installed in Documents/Arduino/libraries...

If nothing else, try uninstalling the custom library and recompiling to see if another error pops up...

cjnsario, 2024-06-27:
Hello. I managed to make the code work by reinstalling the Arduino IDE (1.8.18). Last question. Is there a way to make one screen to display only the delay? I only used one switch and screen and it shows the first effect on the chain. My delay usually goes 4th on the chain.

Colatino, 2024-06-27:
Yes, it is possible and currently the most asked feature!

To do that you'll have to change some significant parts of the code in the ino file. Without investing too much time on it i think you'll need to:

- Change the NUM_SLOTS and NUM_PEDALS constant to 1 in the g1xfour.h

- Change the [parse_patch function](https://github.com/Colatino/PicoZoom/blob/bacb6bfe1ef7cec949cd462afc0da786154a8fa0/src/beta/beta.ino#L240) to only store an effect if it is a delay (I already check for this in [these lines](https://github.com/Colatino/PicoZoom/blob/bacb6bfe1ef7cec949cd462afc0da786154a8fa0/src/beta/beta.ino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) but you'll have to figure out how to do this before), maybe something like this will do:
```
if (index > -1) {
        current_patch.delay[i] = false;
        for (int j = 0; j < N_DELAYS; j++) {
          if (delay_ids[j] == id) {
            current_patch.delay[i] = true;
            break;
          }
        }
        // Check if it is a delay and stores the correct delay slot to manipulate it
        if (current_patch.delay[i]){
            current_patch.effects[i] = effects[index];
            current_patch.states[i] = state;
            current_patch.slots[i] = current_patch.cur_slot;
            break;
        }
        current_patch.cur_slot += effects[index].nslots;
      }
```
I have not tested this but i think this is the way to go. If it works you'll be able to toggle the delay on/off and also change the tempo (and the second tempo if it is that kind of effect).

I would be pleased if you could test it and report back if that worked

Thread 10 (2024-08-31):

Energia

GhermanX, 2024-08-31:
Boa noite. Primeiro gostaria de agradecer pelo projeto. É incrível. Parabéns e mto obg por disponibilizar.

Queria saber se ja testou ou se existe a possibilidade de funcionar por meio de bateria de litium, bateria 9v ou pilhas. Tem ideia de como fazer?

Colatino, 2024-09-01:
Boa noite, amigo!

Não é uma coisa muito difícil de conseguir fazer, era algo que eu tinha planejado fazer, mas por diversas questões externas ao projeto acabei não implementando.

Pra conseguir fazer isso é preciso adicionar a bateria e um módulo carregador. Se for mais que 5v é preciso um regulador de tensão pra alimentar a rpi pico já que ela só aceita entre 3,3 e 5v.

GhermanX, 2024-09-01:
Pesquisando aqui encontrei num site gringo que para usar uma de 9 v basta um LM 7805 pra converter para os 5v e um diodo. Em breve vou adquirir os materiais pra tentar construir e usar na minha A1XFour.

Pensei tambem em adicionar uns leds.

Se eu conseguir fazer te informo aqui.
Muito obg

GhermanX, 2024-10-06:
Boa noite meu querido. Se puder, me tire algumas dúvida por favor. Fiz o processo indicado e foi concluído com a mensagem:

O sketch usa 84548 bytes (4%) de espaço de armazenamento para programas. O máximo são 2093056 bytes.
Variáveis globais usam 92172 bytes (35%) de memória dinâmica, deixando 169972 bytes para variáveis locais. O máximo são 262144 bytes.
Resetting COM11
Converting to uf2, output size: 337408, start address: 0x2000
Scanning for RP2040 devices
Flashing G: (RPI-RP2)
Wrote 337408 bytes to G:/NEW.UF2

Após isso, montei o esquema conectando apenas uma tela Oled para testar, mas parece não funcionar.
As dúvidas são:

Após a conclusão no Arduino IDE, algum LED da Raspberry é aceso? Como saber que deu certo?
Preciso conectar as 5 telas Oleds para funcionar?
O multiplexador que tenho é um PCA ao inves de TCA. Tem alguma influência?

Desde ja muito obrigado.

GhermanX, 2024-10-07:
Boa noite @Colatino , mais uma dúvida para completar as anteriores...

O multiplexador que tenho é um PCA9548A ao invés de TCA9548A. Tem alguma influência? Precisa ser exatamente o TCA?
Porque creio que compilou corretamente como mostrado na imagem anterior. Mas após ligado, não aparece nada na tela oled.

Desde ja agradeço.

Colatino, 2024-10-08:
Boa tarde!

Não é necessário qualquer tela oled ligada para o sistema funcionar, mas elas servem como guia para saber o que está sendo controlado.

Quando tudo correu bem e você liga o sistema as telas de oled devem exibir uma linha branca grossa atravessando o centro, igual à que está no último pedal da direita. Se tiver as 5 telas, devem aparecer as 5 linhas, uma em cada. Se não aparecerem as linhas então algo não está correto.
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

Em relação ao PCA9548A, aparentemente eles são intercambiáveis mas não posso afirmar com certeza absoluta.

Enquanto estava construindo o sistema eu tive que revisar as ligações mais de uma vez para ter certeza de que tudo estava funcionando. Uma dica talvez seja criar um sketch do zero e testar a tela oled com o PCA e ver se os comandos são iguais aos do TCA.

Você fez alguma alteração no código? Mudou algum pino de lugar?

GhermanX, 2024-10-09:
Boa noite.

O Raspberry q eu utilizei é um não original. Um VCC-GND.COM YD-RP2040. Então resolvi fazer um teste criando um sketch e utilizando alguns outros códigos simples do Adafruit_SSD1306 e conectando somente a placa e o oled, mesmo assim não houve nenhuma resposta.

Creio que o problema está na placa ou nos oleds, ja que todos os codigos que utilizei, compilam corretamente. Mas comprar 5 oleds com defeito seria mt azar rsrs.

Vou adquirir uma Raspberry Pico original e voltar a testar. Acredito que seja um problema de hardware.

Além do mais, quanto mais eu simular o seu projeto, creio que maior será o sucesso.

Quando a Raspberry nova chegar eu volto a testar, inclusive o PCA.

Mais uma vez muito obrigado por sua atenção. Assim que eu voltar a testar, lhe informo os resultados.

GhermanX, 2024-10-17:
Boa tarde @Colatino. Tudo bom?
Passando aqui pra mostrar umas coisas e tirar uma provável ultima dúvida.
Como eu tinha dito antes, possuo uma **A1XFour** e dp dos problemas que te informei antes, consegui fazer funcionar.

Algumas observações são:

1- Pra que os Oleds ligassem, tive que conectar os 5. Eu estava sempre testando conectando uma só e não dava certo.

2 -  Depois de conectar a pedaleira, ela só reconheceu a programação dpois que mudei essa linha abaixo.
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

3 - Depois disso ela ligou corretamente e reconheceu a Pedaleira. Só que o sistema não reconhece as simulações de violão. Estas que listei abaixo.
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

4- Os Patches que incluem as simulações de violão, ficam como se o bloco tivesse vazio ou em outras vezes, aparece erroneamente o nome de algum outro efeito aleatório.
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

Creio que esse é o ultimo detalhe que teria que resolver. Você pode me ajudar a fazer que o programa reconheça esses efeitos de violão?

Desde ja agradeço a atenção.

Colatino, 2024-10-17:
Boa tarde!

Descobertas interessantes...

Em relação à placa que você tinha  VCC-GND.COM YD-RP2040, conseguiu funcionar com ela?

Sobre os itens mais recentes:
1 - Eu não conseguia ver motivo para não funcionar com apenas um Oled (ou até sem nenhum) mas analisando novamente o código creio que o procedimento de inicialização das telas deve exigir um retorno dela... se alguma não confirmar o funcionamente provavelmente interrompe a execução do código...

2 - Como só havia testado com a G1Four/G1XFour a função handle_identification só retornava ```true``` caso fosse uma delas. Sua modificação no código está permitindo qualquer pedaleira mesmo que a identificação esteja incorreta pois você inseriu um ```return true``` depois dos if..else. Estou fazendo a correção no código para o comportamento correto mas pode copiar o código abaixo para a função handle_identification que deve funcionar:
```
bool handle_identification() {
  if (sysex_message.message[5] == 0x6e && sysex_message.message[6] == 0x00) {
    uint8_t temp = sysex_message.message[7];
    if (temp == 0x00) {
      //Serial.println("G5n is currently unsupported");
    } else if (temp == 0x02) {
      //Serial.println("G3n is currently unsupported");
    } else if (temp == 0x04) {
      //Serial.println("G3Xn is currently unsupported");
    } else if (temp == 0x0c) {
      //Serial.println("This is a G1Four");
      return true;
    } else if (temp == 0x0d) {
      //Serial.println("This is a G1XFour");
      return true;
    } else if (temp == 0x0e) {
      //Serial.println("B1Four is currently unsupported");
    } else if (temp == 0x0f) {
      //Serial.println("B1XFour is currently unsupported");
    } else if (temp == 0x10) {
      //Serial.println("GCE-3 is currently unsupported");
    } else if (temp == 0x11) {
      Serial.println("This is a A1Four");
      return true;
    } else if (temp == 0x12) {
      Serial.println("This is a A1XFour");
      return true;
    } else {
      //Serial.println("Unidentified pedal");
    }
    return false;
  }
  return false;
}
```

3 - Como não tenho as outras pedaleiras não consegui testar. Há relatos de que nem todas as funções da B1Four/XFour estavam disponíveis através de comandos MIDI, esse pode ser o caso para os efeitos que você relatou. Infelizmente não tenho como testar aqui. Talvez algum problema ou recurso específico da A1XFour impeça a comunicação MIDI, ou algum formato diferente para o efeito.

GhermanX, 2024-10-17:
Boa noite

Inicialmemte não consegui que rodasse na VCC-GND.COM YD-RP2040, mas assim que funcionou na Placa original que comprei, acabei n mexendo mais nela. Talvez posteriormente eu tente para tirar a dúvida total.

Obrigado pelo código atualizado do handle_identification, vou copiar aqui e compilar outra vez.

Quanto aos efeitos que não funcionam, é realmente uma pena.

Vou dar andamento aqui no projeto. Tentarei colocar a bateria e testar a possibilidade de utilizar uns leds endereçáveis.

Qualquer novidade ou conclusão aqui vou lhe informando.

Mais uma vez, mto obrigado pela atenção.

Colatino, 2024-10-18:
Em relação aos efeitos que não funcionam, se eu tivesse a A1Four comigo o que eu faria era tentar descobrir se existe um comando específico que seja diferente desses que já estão no código.

A forma de fazer isso é conectar a pedaleira ao computador e ao Guitarlab ou Tonelib Zoom e utilizar um monitor serial para inspecionar a comunicação entre o Pc e a pedaleira.

Depois de tudo conectado você navega no software até o patch com o efeito que deseja descobrir e ativa e desativa o efeito e observa qual comando foi enviado pelo PC.

Algumas das funções que implementei foram decifradas desse jeito...

GhermanX, 2024-10-19:
Boa noite @Colatino. Depois que conectei os footswitchs, identifiquei mais algumas coisas.

Se esses simuladores de Violão forem o **efeito 1** na cadeia de pedais, acontece o seguinte:
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
GhermanX, 2024-10-23:
Boa noite.
_("Acho que você levou meu conselho muito ao pé da letra hehe")_
Acho que até demais rsrsrs

Daqui a pouco vou fazer as alterações aqui e assim que concluir te envio o feedback.

Mto obgd pela paciência e disponibilidade. Agradeço mt

GhermanX, 2024-10-23:
Fiz as alterações. e compilou corretamente. Mas aconteceram algumas inconsistências.

1-  Quando todos os efeitos estão ativos e pressiono o FootSwitch 1, a tela oled responde imediatamente, mas o LED leva entre 5 e 6 segundos para acender.

2- Qnd qualquer dos efeitos do 2º a 5º está desativado, o FootSwwitch 1 responde perfeitamente ao acionamento, ligando e desligando o LED e o efeito instantaneamente.

3- Pressionar os FootSwitchs 2, 3, 4 ou 5, faz com que a tela 1 responda colocando ou tirando a faixa do meio.
Depois de 5 a 6 segundos,  a tela Oled e o LED corretos são acionados e a tela 1 volta ao que estava antes.

Acha que eu possa ter deixado passar alguma coisa?

Colatino, 2024-10-23:
Esse é um comportamento inesperado, pode ser algum problema elétrico, talvez interferência das ligações dos leds com os oleds.

Esse tempo de 5 a 6 segundos para resposta é bem estranho... tentou colocar somente 1 led de cada vez? Remover todos os leds e deixar só 1 em cada posição.

GhermanX, 2024-10-23:
Boa tarde meu querido.

Sim. Testei primeiramente com um led só e ai fui colocando um led de cada vez, testando gradualmente e sempre acontece a mesma coisa, não importando a quantidade de leds conectados.

Em todos os casos o 1º efeito da cadeia aciona erroneamente e após 5 a 6 segundos ele volta ao normal e o efeito correto é acionado.

Colatino, 2024-10-23:
Quando você liga o sistema os leds acendem em sequência e depois de um segundo apagam na mesma sequência?

GhermanX, 2024-10-23:
Sim, qnd ligo, tanto os LEDs quanto as telas Oled ligam em sequencia. 1 segundo depois os LEDs desligam também em sequencia e os Oleds se mantém ligados com as faixas no meio.

GhermanX, 2024-10-25:
Boa noite
Agora a noite apaguei todo o código do arquivo beta.ino. Abri, copiei e colei o código que tem aqui no seu repo.

Após isso refiz vagarosamente todo o processo dos Leds que me enviou. e pra minha alegria e tranquilidade, funcionou perfeitamente.

Não sei onde estava o erro, mas resolveu rs.

Muito obgdo pela ajuda e disponibilidade. Nas próximas semanas vou tentar concluir o projeto e te envio o resultado completo.

Abraço meu querido.

Colatino, 2024-10-25:
Opa! Bom saber que tudo funcionou... eu não tinha testado o código mas com seu feedback já vou fazer as alterações para deixar formalizado.

Colatino, 2024-11-29:
Ficou muito bom! A ideia do led foi bacana e já fica como solução para quem quiser usar.

Talvez eu faça uma simplificação pra quem não quiser usar telas, fica só o led pra indicar o acionamento do efeito.

GhermanX, 2024-11-29:
Uma boa idéia.
Utilizei Leds endereçáveis com resistor de 220 em cada pra obter menos brilho e não atrapalhar mto a visão das telas e nem ofuscar os olhos.

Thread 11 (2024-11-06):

Loop e rythm

Willsnow12, 2024-11-06:
Mano, primeiramente parabens ai pelo projeto. Excelente.

Vi que vc conseguiu fazer com que sua controladora altere os BPM como um Tap tempo. Por isso gostaria de saber se existe alguma maneira de controlar o Loop ou Rythm da G1Four?
Ao menos ativar e desativar ele sem precisar abaixar.

Colatino, 2024-11-06:
Infelizmente não dá pra fazer vida comando MIDI ou é algum comando muito obscuro que ainda não foi descoberto.

Uma alternativa seria abrir a pedaleira e fazer um hack de hardware, soldando um fio nos contatos dos botões adequados

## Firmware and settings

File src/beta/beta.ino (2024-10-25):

/*
 * The MIT License (MIT)
 *
 * Copyright (c) 2022 André Colatino (https://github.com/Colatino/picozoom)
 *
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
 * This file is part of the PicoZoom project.
 */

#include <MIDI.h>
// pio-usb is required for rp2040 host
#include "pio_usb.h"
#define HOST_PIN_DP 2 // Pin used as D+ for host, D- = D+ + 1

#include "Adafruit_TinyUSB.h"
#define LANGUAGE_ID 0x0409 // English
// USB Host object
Adafruit_USBH_Host USBHost;

// Uncomment the line that corresponds to your pedal
// #include "g1xfour.h"
// #include "g1four.h"
#include "a1xfour.h"
// #include "b1four.h"
// #include "b1xfour.h"
// #include "b3n.h"
// #include "g3n.h"
// #include "g3xn.h"
// #include "g5n.h"

#include "oled.h"
#include "footswitch.h"

// holding device descriptor
tusb_desc_device_t desc_device;

static uint8_t midi_dev_addr = 0;
static bool device_mounted = false;
static bool init_core1 = false;
// String manufacturer, product;

static bool sysex_complete = false;

uint8_t whoareyou[] = {0x7e, 0x00, 0x06, 0x01};
uint8_t editoron[] = {0x52, 0x00, PEDAL_ID, 0x50};
uint8_t editoroff[] = {0x52, 0x00, PEDAL_ID, 0x51};
uint8_t patch_download_current[] = {0x52, 0x00, PEDAL_ID, 0x29};
uint8_t toggle_effect[] = {0x52, 0x00, PEDAL_ID, 0x64, 0x03, 0x00, 0x00, 0x00, 0x00, 0x02, 0x00, 0x00, 0x00};
uint8_t set_param[] = {0x52, 0x00, PEDAL_ID, 0x64, 0x03, 0x00, 0x00, 0x00, 0x00, 0x00, 0x00, 0x00, 0x00};
int sequence = 0;

struct Patch
{
  uint8_t cur_slot = 0;
  uint8_t n_effects = 0;
  uint8_t slots[NUM_SLOTS];
  bool states[NUM_SLOTS];
  bool delay[NUM_SLOTS];
  bool xpedal[NUM_SLOTS];
  Effect effects[NUM_SLOTS];
};

// Number of switches and screens - for now each switch has to be linked to an oled screen
int switch_pins[] = {5, 6, 7, 8, 9}; // GPIO pins on the pico the switches are attached to
FootSwitch footswitch[NUM_PEDALS];
int buses[] = {7, 6, 5, 4, 3}; // Buses on the TCA9548A the oled screens are attached to
Oled oleds[NUM_PEDALS];

bool hasLeds = true;                            // Set this to false if not using LEDs
int ledPins[NUM_PEDALS] = {10, 11, 12, 13, 14}; // Change these pins as needed

Patch current_patch;

typedef enum
{
  EMPTY,
  READING,
  COMPLETE
} message_state_t;

typedef enum
{
  IDLE,
  WAITING,
  BUSY
} core_state_t;

typedef enum
{
  DISCONNECTED,
  CONNECTED,
  READY,
  IDENTIFIED,
  IDENTIFIED_NOT_SUPPORTED,
  EDITOR_ON
} pedal_usb_state_t;

typedef enum
{
  NONE,
  IDENTIFY_REQUEST,
  IDENTIFY_PENDING,
  IDENTIFY_RECEIVED,
  EDITOR_ON_REQUEST,
  EDITOR_ON_PENDING,
  EDITOR_ON_RECEIVED,
  CURRENT_PATCH_REQUEST,
  CURRENT_PATCH_PENDING,
  CURRENT_PATCH_RECEIVED,
  CURRENT_PATCH_UNPACK,
  CURRENT_PATCH_UNPACKED,
  CURRENT_PATCH_PARSE,
  CURRENT_PATCH_PARSED,
  CURRENT_PATCH_CHANGED,
  SET_PARAM_REQUEST,
  SET_PARAM_PENDING,
  SET_PARAM_RECEIVED,
  TOGGLE_EFFECT_REQUEST,
  TOGGLE_EFFECT_PENDING,
  TOGGLE_EFFECT_RECEIVED

} core_task_t;

core_state_t core0_state = IDLE;
core_task_t core0_task = NONE;
core_state_t core1_state = IDLE;
core_task_t core1_task = NONE;

volatile pedal_usb_state_t usb_state = DISCONNECTED;

struct Sysex
{
  uint8_t message[1024];
  int size = 0;
  message_state_t status = EMPTY;
} sysex_message;

struct PChange
{
  uint8_t message[3];
  message_state_t status = EMPTY;
} pc_message;

Sysex unpacked;

void toggle_leds(int i,bool state){
  if (hasLeds){
    digitalWrite(ledPins[i],state);
  }
}

int get_effect_by_id(long id)
{
  for (int i = 0; i < NEFFECTS; i++)
  {
    if (effects[i].id == id)
    {
      return i;
    }
  }
  return -1;
}

// HELPER FUNCTIONS
// Send a new task to the other core
// core0 <-> core1
bool core_queue_push(uint32_t new_task)
{
  return rp2040.fifo.push_nb(new_task);
}

// Get a task from the other core
// core0 <-> core1
// return true on success
bool core_queue_pop(uint32_t *dest)
{
  if (rp2040.fifo.available() > 0)
  {
    *dest = rp2040.fifo.pop();
    return true;
  }
  return false;
}
// CORE 0
// handles functions other than USB communications (switches, displays, data parsing...)

bool handle_identification()
{
  if (sysex_message.message[5] == 0x6e && sysex_message.message[6] == 0x00)
  {
    uint8_t temp = sysex_message.message[7];
    if (temp == 0x00)
    {
      // Serial.println("G5n is currently unsupported");
    }
    else if (temp == 0x02)
    {
      // Serial.println("G3n is currently unsupported");
    }
    else if (temp == 0x04)
    {
      // Serial.println("G3Xn is currently unsupported");
    }
    else if (temp == 0x0c)
    {
      // Serial.println("This is a G1Four");
      return true;
    }
    else if (temp == 0x0d)
    {
      // Serial.println("This is a G1XFour");
      return true;
    }
    else if (temp == 0x0e)
    {
      // Serial.println("B1Four is currently unsupported");
    }
    else if (temp == 0x0f)
    {
      // Serial.println("B1XFour is currently unsupported");
    }
    else if (temp == 0x10)
    {
      // Serial.println("GCE-3 is currently unsupported");
    }
    else if (temp == 0x11)
    {
      Serial.println("This is a A1Four");
      return true;
    }
    else if (temp == 0x12)
    {
      Serial.println("This is a A1XFour");
      return true;
    }
    else
    {
      // Serial.println("Unidentified pedal");
    }
    return false;
  }
  return false;
}

// Lookup the sysex for a specific entry position
int find_section_index(const char *section)
{
  for (int i = 0; i < unpacked.size; i++)
  {
    if (unpacked.message[i] == section[0] && unpacked.message[i + 1] == section[1] && unpacked.message[i + 2] == section[2] && unpacked.message[i + 3] == section[3])
    {
      return i;
    }
  }
  return -1;
}

// Decode the sysex 7 to 8 bits
bool unpack(int start_byte)
{
  Sysex tounpack;
  for (int i = start_byte; i < sysex_message.size; i++)
  {
    tounpack.message[i - start_byte] = sysex_message.message[i];
  }
  unpacked.size = midi::decodeSysEx(tounpack.message, unpacked.message, sysex_message.size - start_byte);
  if (unpacked.size > 0)
  {
    return true;
  }
  else
  {
    return false;
  }
}

// Parse patch data
void parse_patch()
{
  // Check if it is a Patch message (look PTCF at start)
  if (find_section_index("PTCF") > -1)
  {
    // Handle patch file
    //  Useful data is between EDTB and PPRM keywords
    int edtb_start = find_section_index("EDTB") + 4;
    int edtb_end = find_section_index("PPRM");
    int neff = unpacked.message[edtb_start] / 24;
    current_patch.n_effects = neff;
    current_patch.cur_slot = 0;
    for (int i = 0; i < neff; i++)
    {
      long aux = unpacked.message[edtb_start + (7 + i * 24)] << 24 | unpacked.message[edtb_start + (6 + i * 24)] << 16 | unpacked.message[edtb_start + (5 + i * 24)] << 8 | unpacked.message[edtb_start + (4 + i * 24)];
      long id = (aux >> 1) & 0xfffffff;
      int index = get_effect_by_id(id);
      bool state = aux & 1;
      if (index > -1)
      {
        current_patch.effects[i] = effects[index];
        current_patch.states[i] = state;
        current_patch.slots[i] = current_patch.cur_slot;
        current_patch.delay[i] = false;
        for (int j = 0; j < N_DELAYS; j++)
        {
          if (delay_ids[j] == id)
          {
            current_patch.delay[i] = true;
            break;
          }
        }
        current_patch.xpedal[i] = false;
        for (int j = 0; j < N_X_PEDALS; j++)
        {
          if (xpedal_ids[j] == id)
          {
            current_patch.xpedal[i] = true;
            break;
          }
        }

        current_patch.cur_slot += effects[index].nslots;
        // Serial.printf("Effect %s with id %d is %s uses %d slots and has %d parameters\r\n", current_patch.effects[i].fxname, id, state ? "enabled\0" : "disabled\0", current_patch.effects[i].nslots, current_patch.effects[i].nparam);
      }
    }
  }
  unpacked.size = 0;
  sysex_message.size = 0;
  sysex_message.status = EMPTY;
}

void set_effect_toggled(uint8_t fxslot, uint8_t param, bool state)
{
  // Change in fx parameter
  uint8_t fxindex = 0;
  for (int i = 0; i < current_patch.n_effects; i++)
  {
    if (current_patch.slots[i] == fxslot)
    {
      fxindex = i;
      break;
    }
  }
  if (param == 0)
  {
    // Toggled states
    current_patch.states[fxindex] = state;
    oleds[fxindex].clear();
    oleds[fxindex].draw_effect(current_patch.effects[fxindex].fxname, current_patch.states[fxindex]);
    oleds[fxindex].draw();
    toggle_leds(fxindex,current_patch.states[fxindex]);
  }
  else if (param == 1)
  {
    // Don't know what it is, better refresh patch
    // Patch/chain updated - better refresh
    core0_task = CURRENT_PATCH_REQUEST;
  }
  else
  {
    // Changed parameter - ignore for now
    param -= 2;
    // Serial.printf("Changed value of parameter %s\r\n", current_patch.effects[fxindex].params[param].parname);
  }
}

// Parse SysEx messages
void parse_sysex()
{
  // for (int i = 0; i < sysex_message.size; i++) {
  //   Serial.printf("%x ", sysex_message.message[i]);
  // }
  // Serial.println("");
  sysex_message.status = EMPTY;
  if (sysex_message.message[3] == 0x64)
  {
    if (sysex_message.message[4] == 0x03)
    {
      // Seems that 5th byte = 1 whem pedal answers
      // Pedal informing of a change in patch/effect parameters
      if (sysex_message.message[6] < 9)
      {
        // Change in fx parameter
        set_effect_toggled(sysex_message.message[6], sysex_message.message[7], sysex_message.message[8]);
      }
      else if (sysex_message.message[6] == 0x09)
      {
        // Changed patch name - ignore for now
      }
      else if (sysex_message.message[6] == 0x0a)
      {
        if (sysex_message.message[7] == 0x01)
        {
          // Discard untill next 0x52
          for (int k = 7; k < sysex_message.size; k++)
          {
            if (sysex_message.message[k] == 0x52 && sysex_message.message[k + 2] == 0x6e && sysex_message.message[k + 3] == 0x64 && sysex_message.message[k + 4] == 0x03)
            {
              set_effect_toggled(sysex_message.message[k + 6], sysex_message.message[k + 7], sysex_message.message[k + 8]);
              break;
            }
          }
        }
        else if (sysex_message.message[7] == 0x02)
        {
          // Changed global tempo
          // TODO - Implement tap tempo
          uint8_t low = sysex_message.message[8];
          uint8_t high = sysex_message.message[9];
          int tempo = high ? 128 + low : low;
          // Serial.println(tempo);
        }
        else if (sysex_message.message[7] == 0x0c)
        {
          // Set tuner frequency - ignore
        }
        else if (sysex_message.message[7] == 0x0f)
        {
          // Toggle autosave - ignore
        }
        else if (sysex_message.message[7] == 0x0)
        {
          // Patch volume - ignore
        }
      }
    }
    else if (sysex_message.message[4] == 0x12)
    {
      // Patch/chain updated - better refresh model
      core0_task = CURRENT_PATCH_REQUEST;
    }
  }
  else if (sysex_message.message[3] == 0x45)
  {
    // Pedal sending current patch - refresh model
    core0_task = CURRENT_PATCH_REQUEST;
  }
}

// Interrupt routine
void isr()
{
  unsigned long aux_time = millis();
  for (int i = 0; i < NUM_PEDALS; i++)
  {
    footswitch[i].set_trigger_state(millis());
  }
}
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
void loop()
{
  // Handles switch presses, calculations and screens
  handle_core0_states_and_tasks();
}

//--------------------------------------------------------------------+
// CORE 1 FUNCTIONS - HANDLE COMMUNICATIONS
// TRY NOT TO CHANGE ANYTHING FROM HERE
//--------------------------------------------------------------------+
// core1's setup
void setup1()
{
  core1_state = BUSY;
  while (!init_core1)
  {
    // wait for core0 to initialize
  }
  // Serial.println("setup1...");
  pio_usb_configuration_t pio_cfg = PIO_USB_DEFAULT_CONFIG;
  pio_cfg.pin_dp = HOST_PIN_DP;
  USBHost.configure_pio_usb(1, &pio_cfg);

  // run host stack on controller (rhport) 1
  // Note: For rp2040 pico-pio-usb, calling USBHost.begin() on core1 will have most of the
  // host bit-banging processing works done in core1 to free up core0 for other works
  USBHost.begin(1);
  // Serial.println("done");
  core1_state = WAITING;
}

// core1's loop
void loop1()
{
  USBHost.task();
  midi_host_task();
}

void handle_core1_states_and_tasks()
{
  if (core1_state == WAITING)
  {
    uint32_t new_task;
    // Got a new task
    if (core_queue_pop(&new_task))
    {
      if (core1_task == NONE)
      {
        if (new_task == IDENTIFY_REQUEST)
        {
          // Serial.println("Sending identify request");
          core1_state = BUSY;
          send_sysex(whoareyou, 4);
          core1_task = IDENTIFY_REQUEST;
        }
        else if (new_task == EDITOR_ON_REQUEST)
        {
          // Serial.println("Sending editor on request");
          core1_state = BUSY;
          send_sysex(editoron, 4);
          core1_task = EDITOR_ON_REQUEST;
        }
        else if (new_task == CURRENT_PATCH_REQUEST)
        {
          // Serial.println("Sending current patch request");
          core1_state = BUSY;
          send_sysex(patch_download_current, 4);
          core1_task = CURRENT_PATCH_REQUEST;
        }
        else if (new_task == TOGGLE_EFFECT_REQUEST)
        {
          // Serial.println("Toggling effect");
          core1_state = BUSY;
          send_sysex(toggle_effect, 13);
          core1_task = TOGGLE_EFFECT_REQUEST;
        }
        else if (new_task == SET_PARAM_REQUEST)
        {
          // Serial.println("Changing param");
          core1_state = BUSY;
          send_sysex(set_param, 13);
          core1_task = SET_PARAM_REQUEST;
        }
      }
    }
    else
    {
      if (core1_task == NONE)
      {
        if (pc_message.status == COMPLETE)
        {
          // Serial.println("Got patch changed");
          if (core_queue_push(CURRENT_PATCH_CHANGED))
          {
            pc_message.status = EMPTY;
          }
        }
      }
    }
  }
  else if (core1_state == BUSY)
  {
    if (core1_task == IDENTIFY_REQUEST)
    {
      if (sysex_message.status == COMPLETE)
      {
        // TODO - Check if successful
        if (core_queue_push(IDENTIFY_RECEIVED))
        {
          core1_task = NONE;
          core1_state = WAITING;
        }
      }
    }
    else if (core1_task == EDITOR_ON_REQUEST)
    {
      if (sysex_message.status == COMPLETE)
      {
        // TODO - Check if successful
        if (core_queue_push(EDITOR_ON_RECEIVED))
        {
          core1_task = NONE;
          core1_state = WAITING;
        }
      }
    }
    else if (core1_task == CURRENT_PATCH_REQUEST)
    {
      if (sysex_message.status == COMPLETE)
      {
        // TODO - Check if successful
        if (core_queue_push(CURRENT_PATCH_RECEIVED))
        {
          core1_task = NONE;
          core1_state = WAITING;
        }
      }
    }
    else if (core1_task == TOGGLE_EFFECT_REQUEST)
    {
      if (sysex_message.status == COMPLETE)
      {
        // TODO - Check if successful
        if (core_queue_push(TOGGLE_EFFECT_RECEIVED))
        {
          core1_task = NONE;
          core1_state = WAITING;
        }
      }
    }
    else if (core1_task == SET_PARAM_REQUEST)
    {
      if (sysex_message.status == COMPLETE)
      {
        // TODO - Check if successful
        if (core_queue_push(SET_PARAM_RECEIVED))
        {
          core1_task = NONE;
          core1_state = WAITING;
        }
      }
    }
  }
}

static void poll_midi_host_rx(void)
{
  if (!device_mounted)
  {
    if (!midi_dev_addr)
    {
      return;
    }
    if (!tuh_midi_configured(midi_dev_addr))
    {
      return;
    }
    if (!device_mounted)
    {
      tuh_descriptor_get_device(midi_dev_addr, &desc_device, 18, clone_descriptors, 0);
    }
    if (tuh_midih_get_num_rx_cables(midi_dev_addr) < 1)
    {
      return;
    }
  }
  else
  {
    tuh_midi_read_poll(midi_dev_addr);
    // if there is data, then the callback will be called
  }
}

static void midi_host_task(void)
{
  poll_midi_host_rx();
  handle_core1_states_and_tasks();
  if (sysex_complete)
  {
    tuh_midi_stream_flush(midi_dev_addr);
    sysex_complete = false;
  }
}

//--------------------------------------------------------------------+
// TinyUSB Host callbacks
//--------------------------------------------------------------------+
void tuh_midi_mount_cb(uint8_t daddr, uint8_t in_ep, uint8_t out_ep, uint8_t num_cables_rx, uint16_t num_cables_tx)
{
  midi_dev_addr = daddr;
  // Serial.println("device connected");
}

/// Invoked when device is unmounted (bus reset/unplugged)
void tuh_umount_cb(uint8_t daddr)
{
  digitalWrite(LED_BUILTIN, LOW);
  midi_dev_addr = 0;
  usb_state = DISCONNECTED;
  device_mounted = false;
  core0_state = IDLE;
  core0_task = NONE;
  core1_state = IDLE;
  core1_task = NONE;
  usb_state = DISCONNECTED;
  for (int i = 0; i < NUM_PEDALS; i++)
  {
    oleds[i].clear();
    // oleds[i].draw_tempo(i,"");
    oleds[i].draw_effect("Bypass", false);
    oleds[i].draw();
    toggle_leds(i,current_patch.states[i]);
  }
  // Serial.println("device disconnected");
}

// Sends SysEx messages
void send_sysex(uint8_t *message, int size)
{
  size += 2;
  uint8_t new_message[size];

  // Add start and end markers for sysex
  new_message[0] = 0xf0;
  for (int i = 0; i < size - 2; i++)
  {
    new_message[i + 1] = message[i];
  }
  new_message[size - 1] = 0xf7;

  // size += 2;
  for (int i = 0; i < size; i++)
  {
    // Serial.printf("%x ", new_message[i]);
  }
  // Serial.println("");

  int numpackets = ceil((double)size / 3.0);
  uint8_t packet[4];
  int index = 0;
  for (int i = 0; i < numpackets; i++)
  {
    for (int j = 0; j < 4; j++)
    {
      // Add CIN
      if (j == 0)
      {
        if (i == numpackets - 1)
        {
          if (size - index == 1)
          {
            // SysEx ends on next byte
            packet[0] == 0x05;
          }
          else if (size - index == 2)
          {
            // SysEx ends on next 2 bytes
            packet[0] == 0x06;
          }
          else
          {
            // SysEx ends on next 3 bytes
            packet[0] = 0x07;
          }
        }
        else
        {
          // SysEx packet start
          packet[0] = 0x04;
        }
      }
      else
      {
        if (index < size)
        {
          // SysEx data
          packet[j] = new_message[index];
        }
        else
        {
          // Fill rest with 0
          packet[j] = 0x00;
        }
        index++;
      }
    }
    // Send 4 byte packets
    tuh_midi_packet_write(midi_dev_addr, packet);
  }
  // Flag as ready to flush
  sysex_complete = true;
}

// Handles received SysEx message
void handle_sysex_rx_cb(uint8_t *packet, uint8_t cin)
{
  if (cin == 4)
  {
    if (sysex_message.status == EMPTY)
    {
      sysex_message.status = READING;
      sysex_message.size = 0;
    }
    if (packet[1] != 0xf0)
    {
      sysex_message.message[sysex_message.size++] = packet[1];
    }
    sysex_message.message[sysex_message.size++] = packet[2];
    sysex_message.message[sysex_message.size++] = packet[3];
  }
  if (cin == 5)
  {
    sysex_message.status = COMPLETE;
  }
  if (cin == 6)
  {
    sysex_message.message[sysex_message.size++] = packet[1];
    sysex_message.status = COMPLETE;
  }
  if (cin == 7)
  {
    sysex_message.message[sysex_message.size++] = packet[1];
    sysex_message.message[sysex_message.size++] = packet[2];
    sysex_message.status = COMPLETE;
  }
}

void handle_cc_rx_cb()
{
  // //Serial.println("CC received");
  // Do nothing
}

void handle_pc_rx_cb()
{
  // //Serial.println("PC received");
  // Possibly changed the current patch
  pc_message.status = COMPLETE;
}
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

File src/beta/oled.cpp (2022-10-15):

/*
 * The MIT License (MIT)
 *
 * Copyright (c) 2022 André Colatino (https://github.com/Colatino/picozoom)
 *
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
 * This file is part of the PicoZoom project.
 */
 
#include "oled.h"

// Constructor
Oled::Oled() {}
//: _display(SCREEN_WIDTH, SCREEN_HEIGHT, &Wire, OLED_RESET) {}

void Oled::begin() {
  _display = Adafruit_SSD1306(SCREEN_WIDTH, SCREEN_HEIGHT, &Wire, OLED_RESET);
  _display.begin(SSD1306_SWITCHCAPVCC, SCREEN_ADDRESS);
}

void Oled::begin(int bus) {
  _bus = bus;
  _display = Adafruit_SSD1306(SCREEN_WIDTH, SCREEN_HEIGHT, &Wire, OLED_RESET);
  Oled::select_bus();

  if (!_display.begin(SSD1306_SWITCHCAPVCC, SCREEN_ADDRESS)) {
    //Serial.printf("Failed to initialize oled on bus %d\r\n",bus);
  }
  //Serial.println("Started");
}

void Oled::select_bus() {
  if (TCA9548A) {
    //Serial.printf("Selecting bus %d\r\n",_bus);
    Wire.beginTransmission(0x70);  // TCA9548A address is 0x70
    Wire.write(1 << _bus);         // send byte to select bus
    Wire.endTransmission();
  }
}

void Oled::draw_effect(const char *fxname, bool state) {
  //Serial.printf("Drawing effect on display at bus %d\r\n",_bus);
  if (state)
    _display.fillRect(0, 3 * SCREEN_HEIGHT / 8, SCREEN_WIDTH, SCREEN_HEIGHT / 4, SSD1306_WHITE);

  if (strcmp(fxname, "Bypass") != 0)
    Oled::draw_text(fxname);

  if (!state)
    _display.fillRect(0, 3 * SCREEN_HEIGHT / 8, SCREEN_WIDTH, SCREEN_HEIGHT / 4, SSD1306_WHITE);
}

void Oled::draw_text(const char *text) {
  _display.setTextColor(SSD1306_WHITE);

  // Text size variables
  int xscale = 5;
  int yscale = 3;
  uint16_t w, h;
  int16_t x1, y1;
  _display.setTextSize(xscale, yscale);

  // Then try to draw the widest text possible (SCREEN_WIDTH-10)
  while (xscale >= 1 && yscale >= 1) {
    _display.getTextBounds(text, 0, 0, &x1, &y1, &w, &h);
    if (w <= SCREEN_WIDTH - 10) {
      break;
    }
    if (w >= SCREEN_WIDTH - 10) {
      xscale--;
    }
    // if (h > SCREEN_HEIGHT) {
    //   yscale--;
    // }
    _display.setTextSize(xscale, yscale);
  }
  // Text position
  int16_t cursorx, cursory;
  cursorx = (SCREEN_WIDTH - w) / 2;
  cursory = (SCREEN_HEIGHT - h) / 2;

  // Draw a black bounding box
  _display.fillRect(cursorx - 1, cursory, w, h, SSD1306_BLACK);

  // Centralize text
  _display.setCursor(cursorx, cursory + 1);
  _display.println(text);
}

void Oled::draw_tempo(int tempo, const char *sufix) {
  String helper = String(tempo);
  helper.concat(" ");
  helper.concat(sufix);
  ////Serial.println(tempo);
  _display.setTextColor(SSD1306_WHITE);

  // Text size variables
  uint16_t w, h;
  int16_t x1, y1;
  _display.setTextSize(2);

  // Centralize text
  _display.setCursor(5, 0);
  _display.println(helper);
}

void Oled::clear() {
  _display.clearDisplay();
}

void Oled::draw() {
  Oled::select_bus();
  _display.display();
  //Serial.println("Drawn");
  _redraw = false;
}

bool Oled::get_redraw() {
  return _redraw;
}

void Oled::set_redraw() {
  _redraw = true;
}

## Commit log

2022-10-11 Add custom tinyusb library
    [picozoom.fzz]
2022-10-11 case files
    [base.3mf, base.stl, top.3mf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]
2022-10-17 add som pedal ids
    [picozoom.fzz]
2023-01-31 Updated pedals ids and slots
2023-03-20 Added a new base
    Added a thicker version of the base (both 3mf and stl v2 files). It has more space for fixing components with screws
    [basev2.3mf, basev2.stl]
2024-10-17 Update
    Updated the code to recognize the A1Four/XFour
    There are some known issues with Acoustic simulator effects not being correctly recognized
    [beta.ino]
2024-10-25 Update beta.ino
    add handling LEDs for state tracking
